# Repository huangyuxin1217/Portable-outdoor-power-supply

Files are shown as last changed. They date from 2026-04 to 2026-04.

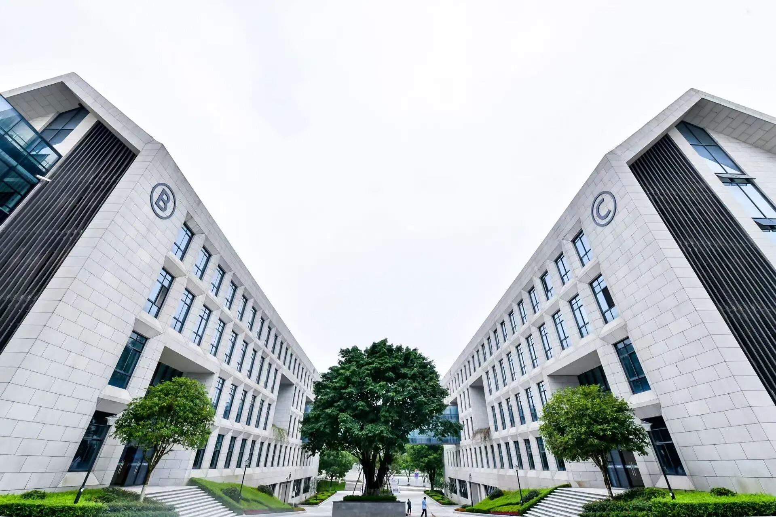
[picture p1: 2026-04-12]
Paper Sculpture Lamp Design/png/微信图片_2025-12-22_202631_440.jpg

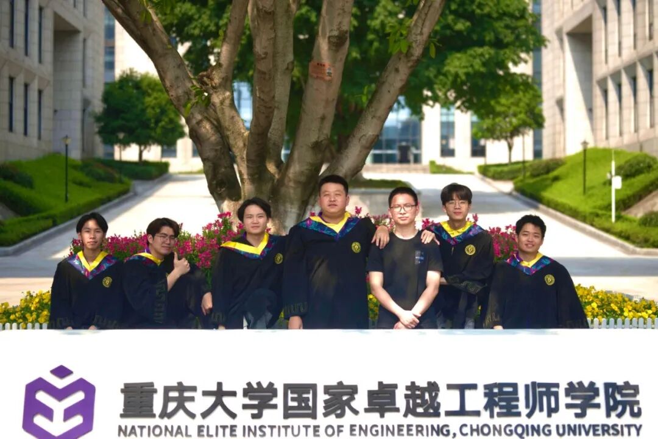
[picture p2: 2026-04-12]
Paper Sculpture Lamp Design/png/640.jpg

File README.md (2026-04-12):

# control-algorithm
This is a project from my sophomore year control algorithm course, which involved building a portable outdoor power supply.Taking the DC Buck power supply engineering case as the application object, through learning methods such as theoretical calculation, simulation, and experiment, strengthen the understanding and application of automatic control theory, and complete the analysis, design, and debugging of the DC power supply control system.

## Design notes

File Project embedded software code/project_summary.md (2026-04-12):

# ESP32 控制数学系统 - 工程总结

本文档总结了当前 ESP32 控制系统的工程架构、运行流程及各核心模块的优化策略。

## 1. 工程架构 (Architecture)

本工程基于 **ESP32** 平台，采用 **FreeRTOS** 实时操作系统架构，实现了多任务并发处理。

### 核心硬件抽象层
*   **主控**: ESP32-WROOM
*   **协处理器通信**: 通过 UART2 与 STM32F103C8T6 通信 (数据采集)
*   **交互**:
    *   **输出**: 0.96寸 OLED (SSD1306), WS2812B 彩灯条, MAX98357A I2S 音频放大器
    *   **输入**: I2S 全向麦克风 (INMP441/SPH0645)

### 软件任务架构
系统通过 FreeRTOS 任务和 Arduino `loop()` 结合的方式运行：

1.  **Main Loop (Core 1)**: 负责高优先级的非阻塞逻辑
    *   Web Server 请求处理
    *   MP3 音频流播放 (`mp3->loop()`)
    *   LED 动画效果计算与刷新
    *   OLED 界面刷新 (500ms 间隔)
    *   语音指令响应逻辑
2.  **Voice Task (Core 1, Pinned)**: 语音识别专用任务
    *   持续读取 I2S 音频流
    *   执行 Edge Impulse 神经网络推理
    *   通过队列 (`voiceQueue`) 发送识别结果
3.  **STM32 Comm Task (Core 1, Pinned)**: 串口通信任务
    *   监听 UART2 接收缓冲区
    *   负责数据帧解析、校验和验证
    *   更新共享数据结构 (互斥锁保护)
4.  **WiFi Reconnect Task (Core 1, Pinned)**: 后台网络维护
    *   监控 WiFi 连接状态
    *   断线自动重连，确保主流程不卡顿

## 2. 程序运行流程 (Execution Flow)

### 2.1 启动流程
1.  **硬件初始化**: 初始化串口、LED、OLED、I2S 总线、SPIFFS 文件系统。
2.  **网络启动**: 尝试连接 WiFi (非阻塞)，成功则启动 Web Server 并播放欢迎音，失败则通过后台任务重试。
3.  **任务创建**: 启动语音识别任务、STM32 通信接收任务、WiFi 守护任务。
4.  **进入主循环**: 开始轮询处理各类事件。

### 2.2 语音控制交互流程
1.  **唤醒**: 用户说出 "Hello" -> 识别成功 -> 播放 "yes.mp3" -> 进入**激活状态** (8秒超时)。
2.  **指令**:
    *   用户说 "KaiDeng" (仅在激活状态有效) -> 打开 LED (黄色) -> 播放 "on.mp3"。
    *   用户说 "GuanDeng" (仅在激活状态有效) -> 关闭 LED -> 播放 "off.mp3"。
3.  **反馈**: 每次识别成功都会通过串口打印置信度，并在 LED 上显示简单的反馈动画（如唤醒时亮蓝灯）。

### 2.3 数据监测流程
1.  **STM32 发送**: 打包电压、电流、温度等传感器数据 -> 添加帧头/帧尾/校验 -> UART 发送。
2.  **ESP32 接收**: `stm32Task` 捕获数据 -> 校验通过 -> 更新全局 `STM32Data` 结构体。
3.  **显示更新**: 主循环每 500ms 读取一次最新数据 -> 刷新 OLED 显示屏 -> 供 Web 端 API 查询。

## 3. 各模块优化 (Optimizations)

### 3.1 语音识别 (Voice Recognition)
*   **滑动窗口机制 (Sliding Window)**: 每次推理仅更新 1/3 的音频数据，保留 2/3 旧数据。这极大提高了对跨窗口关键词的捕捉能力，避免"掐头去尾"导致的识别失败。
*   **数字增益 (Digital Gain)**: 在读取 I2S 数据时通过位移操作 (`raw >> 14`) 调整输入音量，适配不同麦克风灵敏度。
*   **激活词逻辑 (Wake Word)**: 引入 "Hello" 作为激活词，只有唤醒后才响应控制指令，有效防止日常谈话中的误触发。
*   **冷却防抖**: 识别成功后有一秒钟的“不应期”，防止一次发音被连续识别多次。

### 3.2 通信模块 (Communication)
*   **稳健协议**: 设计了包含 `帧头(AA 55)`、`长度`、`校验和`、`帧尾(0D 0A)` 的数据包格式，极大降低了串口通信的误码率和错包率。
*   **线程安全**: 使用 FreeRTOS `Mutex` (互斥锁) 保护共享数据区的读写，防止多任务并发导致的数据竞争。
*   **状态机解析**: 接收逻辑采用状态机模式，能从字节流中精准提取数据帧，具备自动丢弃乱码和错误恢复能力。

### 3.3 系统体验 (User Experience)
*   **非阻塞 WiFi**: WiFi 连接失败不会阻塞系统启动，允许设备在离线状态下正常使用语音和本地控制功能。
*   **Web 控制台**: 提供直观的网页界面 (Vue-like 风格)，支持实时数据监视、颜色拾取器、LED 动效切换和远程消息发送。
*   **OLED 动态显示**: 当收到 Web 端消息时，OLED 会暂时中断监测数据显示消息内容，10秒后自动恢复，提升交互性。

## 4. 总结
该工程成功整合了 **端侧 AI (语音)**、**实时控制 (STM32/LED)** 和 **IoT 网络 (Web)** 三大功能。代码结构清晰，通过任务分离保证了系统的实时性和稳定性，具备较高的实用价值和扩展性。

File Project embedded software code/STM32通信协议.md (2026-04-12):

# ESP32与STM32C8T6通信协议

## 📡 通信接口配置

### 硬件连接
| ESP32引脚 | 功能 | 连接到STM32 |
|---|---|---|
| GPIO16 | RX2  | STM32 TX |
| GPIO17 | TX2  | STM32 RX |
| GND | 地 | STM32 GND  |

### 通信参数
- **串口**: UART2
- **波特率**: 115200 bps
- **数据位**: 8位
- **停止位**: 1位
- **校验位**: 无
- **流控**: 无

---

## 📦 数据帧格式

### 帧结构
```
+------+------+--------+------+------+-----+------+
| 帧头 | 长度 | 数据1  | ... | 数据N | 校验 | 帧尾 |
+------+------+--------+------+------+-----+------+
  2字节  1字节  N字节          1字节  2字节
```

### 字段说明
| 字段 | 长度 | 说明 | 值/范围 |
|---|---|---|---|
| 帧头 | 2字节  | 固定帧头标识 | 0xAA 0x55 |
| 长度 | 1字节  | 数据域长度（不含帧头、校验、尾）| 0-255 |
| 数据域 | N字节  | 实际数据内容 | 见数据定义 |
| 校验 | 1字节  | 校验和（长度+数据域累加和） | 0x00-0xFF |
| 帧尾 | 2字节  | 固定帧尾标识 | 0x0D 0x0A |

---

## 📊 数据定义

### 数据包内容（共12字节数据域）
| 序号 | 参数名称 | 数据类型 | 字节数 | 单位  | 数值范围 | 说明 |
|---|---|---|---|---|---|---|
| 1 | 输出电压反馈 | uint16_t | 2字节  | 0.01V | 0-6553.5V | 高字节在前 |
| 2 | 电池电压采样 | uint16_t | 2字节  | 0.01V | 0-6553.5V | 高字节在前 |
| 3 | 输出电流采样 | uint16_t | 2字节  | 0.01A | 0-655.35A | 高字节在前 |
| 4 | 光敏传感器 | uint16_t | 2字节  | - | 0-4095 | ADC原始值，高字节在前 |
| 5 | 温度 | int16_t  | 2字节  | 0.1℃  | -327.6-327.7℃| 高字节在前，有符号 |
| 6 | 交流市电采样 | uint16_t | 2字节  | 0.1V  | 0-6553.5V | 高字节在前，RMS值  |

**总数据域长度**: 12字节

---

## 📝 完整帧示例

### 示例数据
- 输出电压: 12.34V → 1234 → 0x04D2
- 电池电压: 11.50V → 1150 → 0x047E
- 输出电流: 2.50A → 250 → 0x00FA
- 光敏传感器: 2048 → 0x0800
- 温度: 25.5℃ → 255 → 0x00FF
- 交流市电: 220.0V → 2200 → 0x0898

### 帧结构（十六进制）
```
AA 55                    // 帧头
0C                       // 长度 = 12字节
04 D2                    // 输出电压 = 1234 (12.34V)
04 7E                    // 电池电压 = 1150 (11.50V)
00 FA                    // 输出电流 = 250 (2.50A)
08 00                    // 光敏传感器 = 2048
00 FF                    // 温度 = 255 (25.5℃)
08 98                    // 交流市电 = 2200 (220.0V)
XX                       // 校验和
0D 0A                    // 帧尾
```

### 校验和计算
```c
校验和 = (0x0C + 0x04 + 0xD2 + 0x04 + 0x7E + 0x00 + 0xFA + 0x08 + 0x00 + 0x00 + 0xFF + 0x08 + 0x98) & 0xFF
```

---

## 🔄 通信流程

### STM32发送流程
1. 采集所有传感器数据
2. 按照数据定义组装数据包
3. 计算校验和
4. 添加帧头和帧尾
5. 通过UART发送完整数据帧
6. 建议发送频率: 100ms-1000ms

### ESP32接收流程
1. 监听UART2接收数据
2. 检测帧头 (0xAA 0x55)
3. 读取长度字段
4. 接收数据域
5. 读取校验和和帧尾
6. 验证校验和是否正确
7. 验证帧尾 (0x0D 0x0A)
8. 解析数据并显示/处理

---

## ⚠️ 错误处理

### 可能的错误类型
| 错误类型 | 处理方式 |
|---|---|
| 帧头错误 | 丢弃当前字节，继续搜索帧头 |
| 长度异常 | 丢弃整帧，重新等待 |
| 校验和错误 | 丢弃整帧，计数错误次数 |
| 帧尾错误 | 丢弃整帧，重新等待 |
| 超时 | 清空缓冲区，重新开始 |

### 超时设置
- **字节间超时**: 100ms（两个字节之间的最大间隔）
- **帧超时**: 500ms（从帧头到帧尾的最大时间）

---

## 📈 数据转换说明

### STM32端（发送）
```c
// 电压转换: 实际电压(V) × 100 → uint16_t
uint16_t voltage_data = (uint16_t)(actual_voltage * 100);

// 电流转换: 实际电流(A) × 100 → uint16_t
uint16_t current_data = (uint16_t)(actual_current * 100);

// 温度转换: 实际温度(℃) × 10 → int16_t
int16_t temp_data = (int16_t)(actual_temp * 10);

// 交流电压转换: 实际电压(V) × 10 → uint16_t
uint16_t ac_voltage_data = (uint16_t)(actual_ac_voltage * 10);
```

### ESP32端（接收）
```c
// 电压还原: uint16_t → 实际电压(V)
float voltage = data_u16 / 100.0f;

// 电流还原: uint16_t → 实际电流(A)
float current = data_u16 / 100.0f;

// 温度还原: int16_t → 实际温度(℃)
float temp = data_i16 / 10.0f;

// 交流电压还原: uint16_t → 实际电压(V)
float ac_voltage = data_u16 / 10.0f;
```

---

## 🔧 扩展说明

### 预留扩展
如需增加更多数据，建议：
1. 保持帧头、帧尾、校验算法不变
2. 修改长度字段
3. 在数据域末尾添加新数据
4. 更新本协议文档
5. 保持版本兼容性考虑

### 版本管理
- **当前版本**: V1.0
- **更新日期**: 2025年12月19日
- **维护者**: ESP32控制数学系统项目组

---

## 📌 注意事项

1. **字节序**: 所有多字节数据采用**大端模式**（高字节在前）
2. **数据对齐**: 无需特殊对齐，按顺序排列
3. **异常值**: 当传感器异常时，建议发送特定值（如0xFFFF）表示无效
4. **通信质量**: 建议添加通信成功率统计，便于调试
5. **调试模式**: 建议STM32和ESP32都提供串口输出用于调试验证

---

## 🎯 下一步工作

- [ ] 在ESP32端实现UART2接收解析函数
- [ ] 在ESP32端实现数据结构体定义
- [ ] 在OLED上显示接收到的数据
- [ ] 实现错误检测和统计
- [ ] 添加数据变化监测和告警功能
- [ ] 通过WiFi将数据上传到Web界面

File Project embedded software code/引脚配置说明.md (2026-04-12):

# ESP32 控制数学系统 - 引脚配置说明

## 项目信息
- **开发板**: MH-ET ESP32 DevKit
- **芯片**: ESP32-WROOM-32
- **开发环境**: PlatformIO + Arduino Framework

---

## 引脚配置表

### OLED显示屏 (I2C接口)
| 功能 | ESP32引脚 | 说明 |
|---|---|---|
| SDA | GPIO21 | I2C数据线 (默认I2C引脚) |
| SCL | GPIO22 | I2C时钟线 (默认I2C引脚) |
| VCC | 3.3V | 电源正极 |
| GND | GND | 电源地 |

**OLED规格**:
- 型号: SSD1306 / SSD1309
- 尺寸: 0.96寸 / 2.42寸
- 分辨率: 128x64
- I2C地址: 0x3C

---

### 麦克风 (I2S接口 - INMP441)
| 功能 | ESP32引脚 | 说明 |
|---|---|---|
| SCK  | GPIO26 | 串行时钟 (BCLK) |
| WS | GPIO25 | 字选择 (LRCK) |
| SD | GPIO34 | 串行数据 (DOUT) |
| VCC  | 3.3V | 电源正极 |
| GND  | GND | 电源地 |
| L/R  | GND | 接地选择左声道 (或根据代码配置) |

### LED指示灯
| 功能 | ESP32引脚 | 说明 |
|---|---|---|
| LED  | GPIO2 | 板载蓝色LED (高电平亮/低电平亮视板子而定) |

### WS2812B 彩灯 (预留)
| 功能 | ESP32引脚 | 说明 |
|---|---|---|
| DIN  | GPIO27 | 灯带数据输入 |
| VCC  | 5V | 灯带电源 (注意功率) |
| GND  | GND | 电源地 |

### 扬声器 / 功放 (I2S接口 - MAX98357A)
| 功能 | ESP32引脚 | 说明 |
|---|---|---|
| LRC  | GPIO33 | 字选择 (LRCK) |
| BCLK | GPIO32 | 串行时钟 (BCLK) |
| DIN  | GPIO23 | 串行数据输入 (DIN) |
| VCC  | 5V | 电源正极 |
| GND  | GND | 电源地 |

---

### 串口通信

#### UART0 (USB串口 - 调试用)
| 功能 | ESP32引脚 | 说明 |
|---|---|---|
| TX | GPIO1 (TXD0) | USB转串口发送 |
| RX | GPIO3 (RXD0) | USB转串口接收 |

**用途**: 程序下载、串口调试监视器
**波特率**: 115200

#### UART2 (与 STM32 通信 - 预留)
| 功能 | ESP32引脚 | 说明 |
|---|---|---|
| TX | GPIO17 (TX2) | 发送数据给 STM32 |
| RX | GPIO16 (RX2) | 接收 STM32 数据 |

**用途**: 与 STM32 核心板进行数据交互
**状态**: 预留可用

---

### WiFi 通信
| 功能 | 说明 |
|---|---|
| WiFi模块 | ESP32内置WiFi (2.4GHz) |
| 支持模式 | STA (客户端模式) / AP (热点模式) / STA+AP |
| 当前模式 | STA模式 - 连接到路由器 |
| 占用引脚 | 无需外部引脚 (内部集成) |

**功能**: 
- 连接到WiFi路由器
- 与手机/电脑进行网络通信
- 支持HTTP服务器、TCP/UDP通信

---

## 可用引脚 (未占用)

以下引脚可用于扩展功能:

| 引脚编号 | 类型 | 备注 |
|---|---|---|
| GPIO4 | 输入/输出 | 可用 |
| GPIO5 | 输入/输出 | 可用 |
| GPIO12-15 | 输入/输出 | 启动时需注意电平状态 (MTDI/MTDO等) |
| GPIO18-19 | 输入/输出 | 可用 (VSPI引脚) |
| GPIO35-39 | 仅输入/ADC | 仅输入，支持模拟输入 (GPIO34已用于麦克风) |

---

## 注意事项

### 不可用或受限引脚
- **GPIO0**: 启动模式选择，启动时需为高电平
- **GPIO2**: 启动时需为低电平，板载LED
- **GPIO6-11**: 连接到Flash芯片，**禁止使用**
- **GPIO34-39**: 仅输入，无内部上拉/下拉电阻 

### 电源说明
- **工作电压**: 3.3V逻辑电平
- **供电方式**: USB 5V供电 (板载稳压至3.3V)
- **最大输出电流**: 单个GPIO约40mA，总电流不超过200mA

---

## 功能模块说明

### 1. OLED显示模块
**文件位置**: 
- `include/oled.h` - 头文件
- `src/oled.cpp` - 实现文件

**主要功能**:
- 显示文字、数字
- 绘制图形（线、矩形、圆形）
- 屏幕刷新控制

### 2. WiFi通信模块
**功能**: 
- STA模式连接路由器
- HTTP Web服务器
- 与手机APP进行数据交互

### 3. 串口通信模块（预留）
**用途**: 
- 外部传感器数据读取
- 与其他MCU通信
- 调试输出

---

## 更新日志
- **2025-12-19**: 初始版本，配置OLED和WiFi STA模式

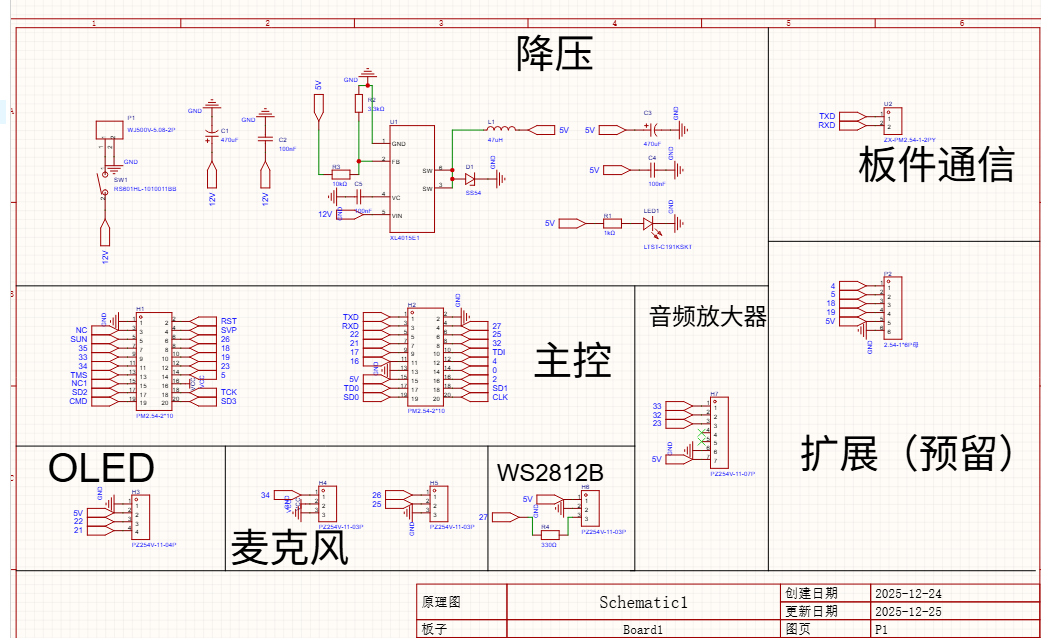
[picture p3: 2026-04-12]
Project Hardware/Schematic diagram.png

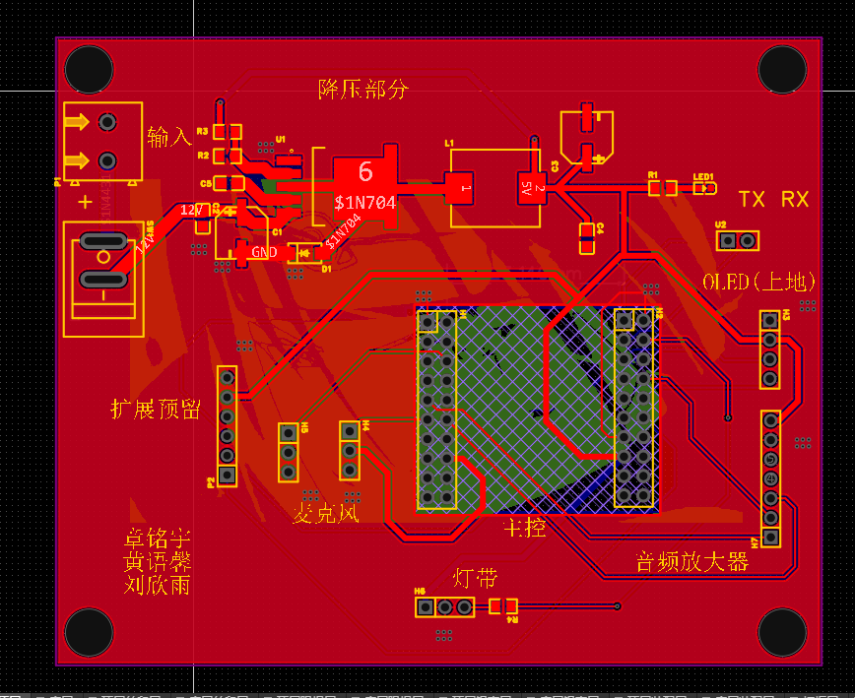
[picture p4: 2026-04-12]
Project Hardware/PCB diagram.png

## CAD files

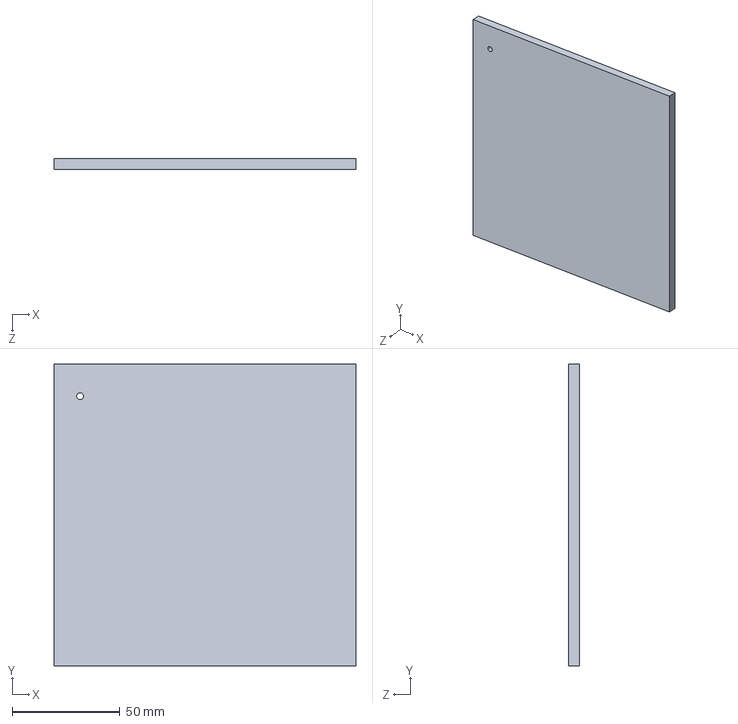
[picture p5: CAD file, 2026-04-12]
Outdoor power supply housing design/亚克力板.SLDPRT
140.0 x 140.0 x 5.00 mm

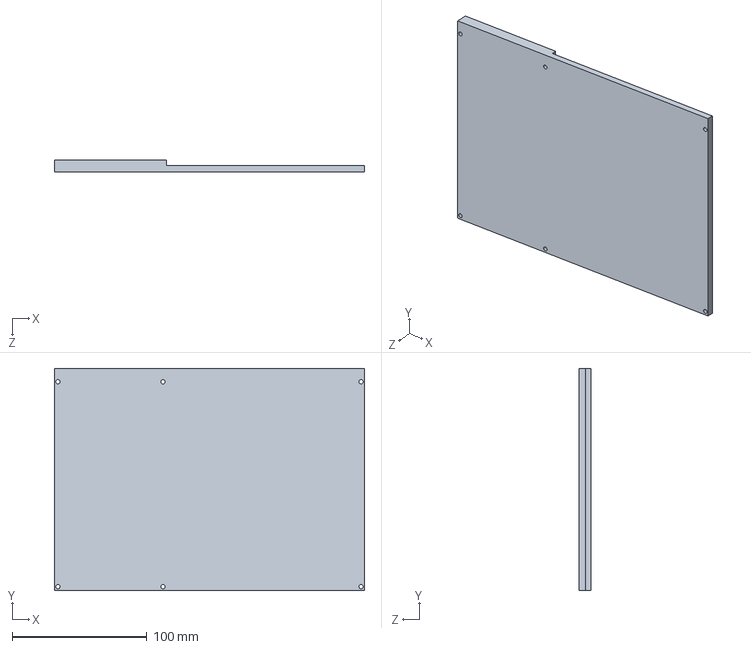
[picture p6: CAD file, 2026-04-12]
Outdoor power supply housing design/外板1.SLDPRT
230.0 x 165.0 x 9.00 mm

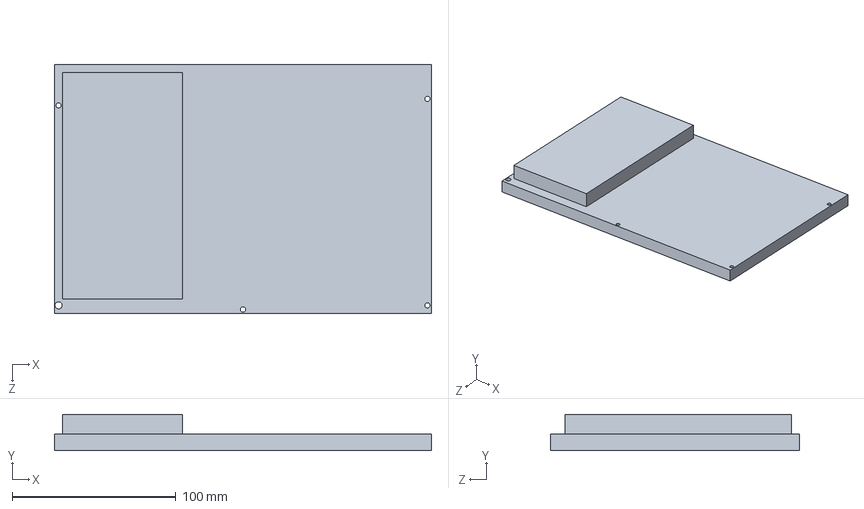
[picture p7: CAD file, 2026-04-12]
Outdoor power supply housing design/外板2.SLDPRT
230.0 x 22.0 x 152.0 mm

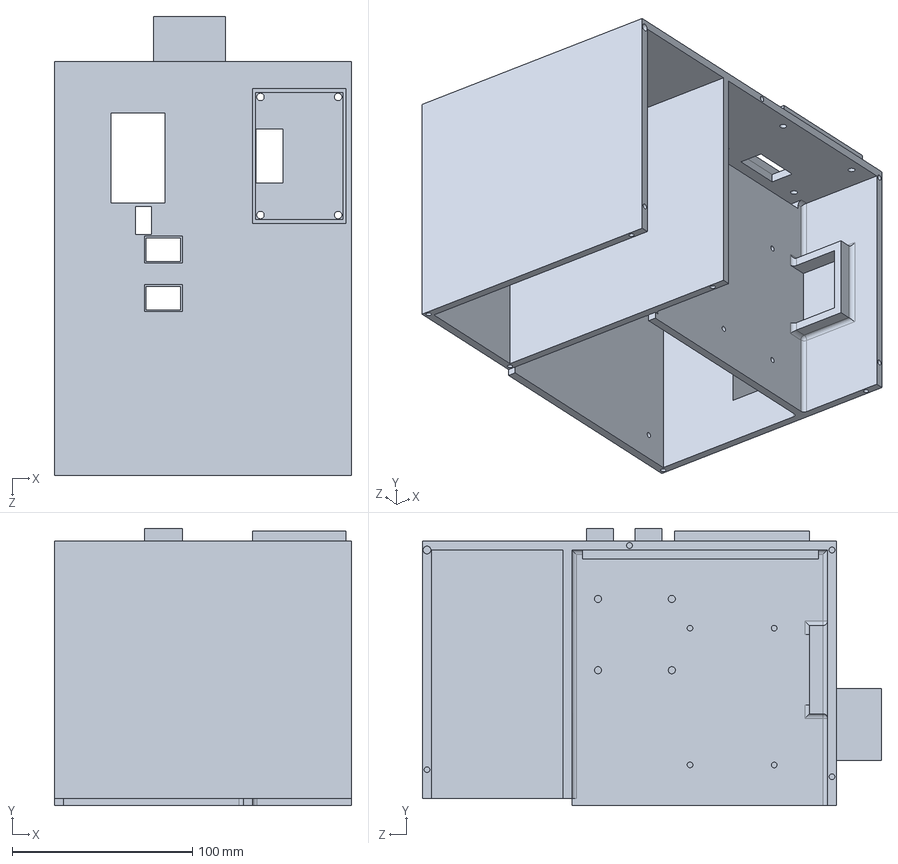
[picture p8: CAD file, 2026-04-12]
Outdoor power supply housing design/外壳1.SLDPRT
165.0 x 154.0 x 255.0 mm

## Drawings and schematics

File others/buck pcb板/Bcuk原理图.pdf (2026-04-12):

# 电源输入

5V-3.3V

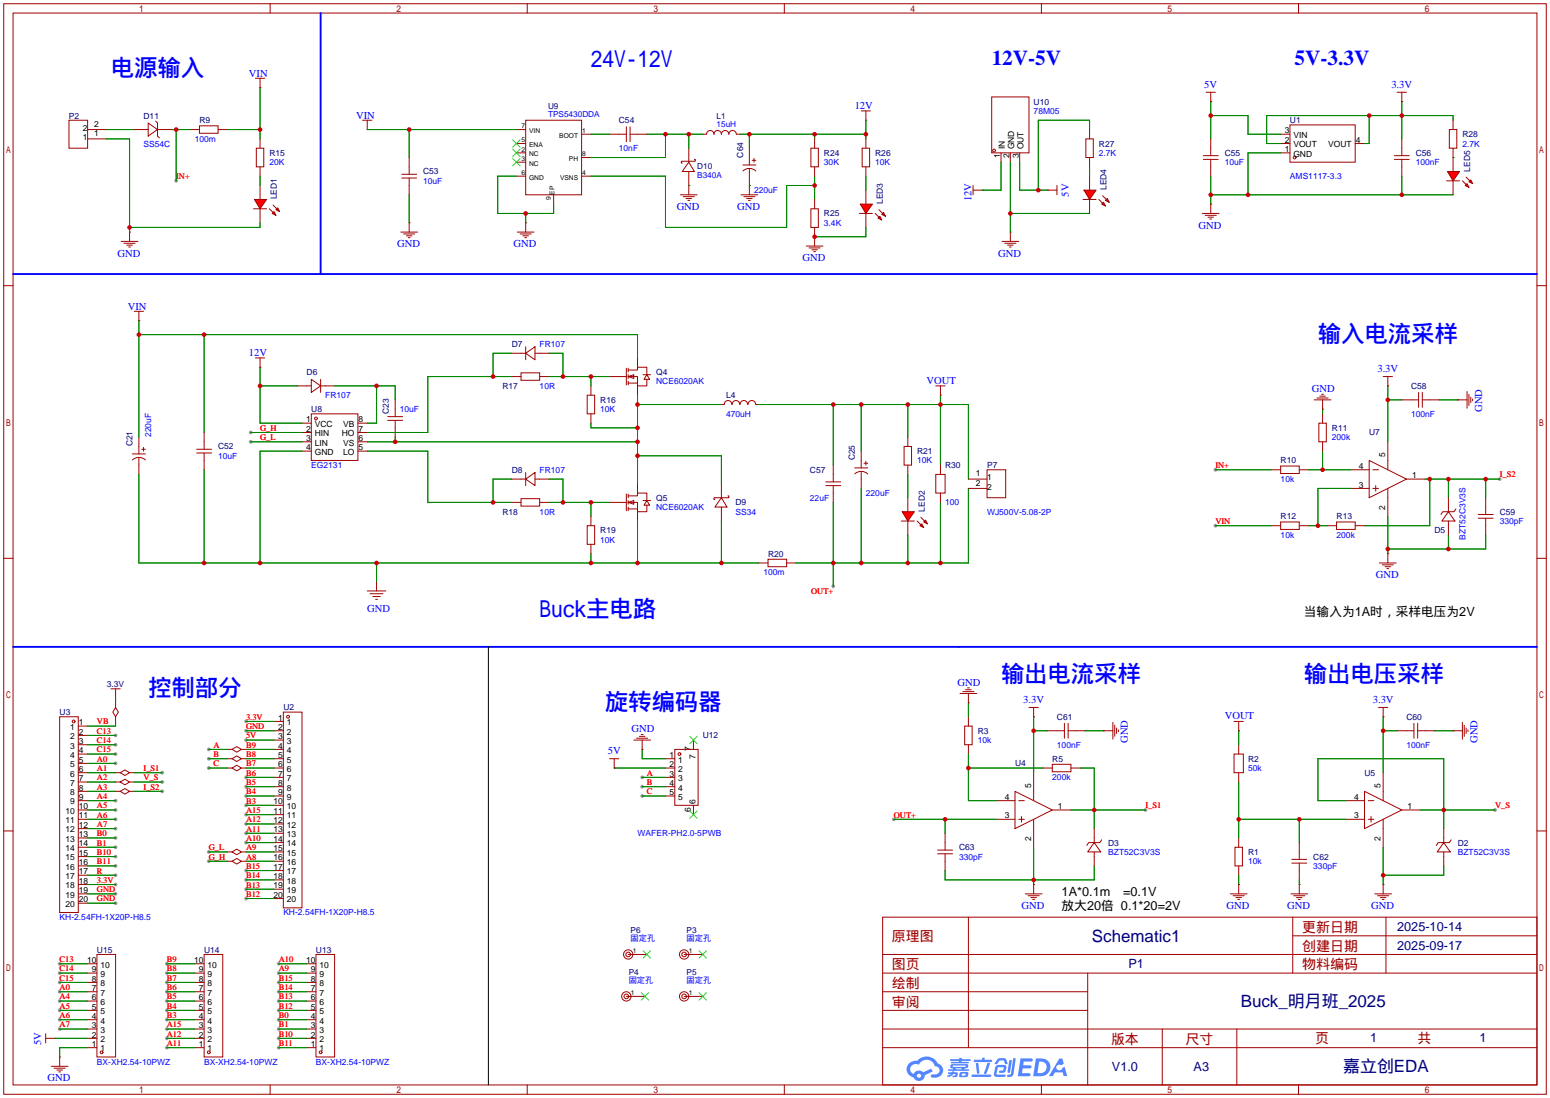
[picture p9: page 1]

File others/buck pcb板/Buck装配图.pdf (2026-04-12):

D11 L1

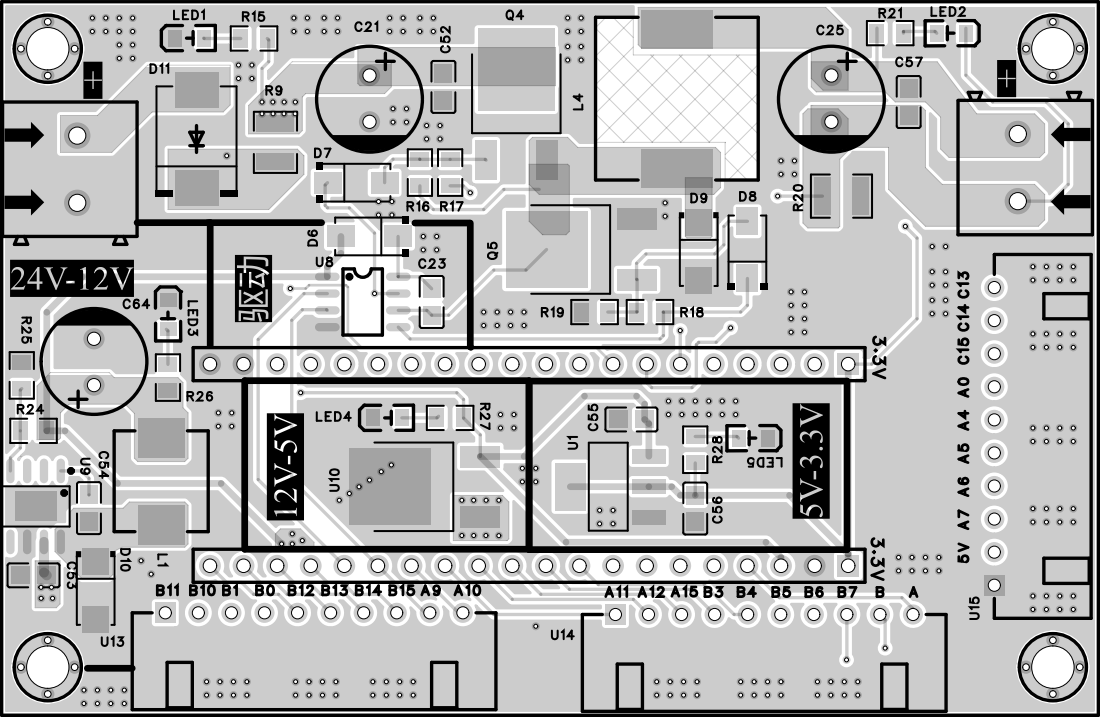
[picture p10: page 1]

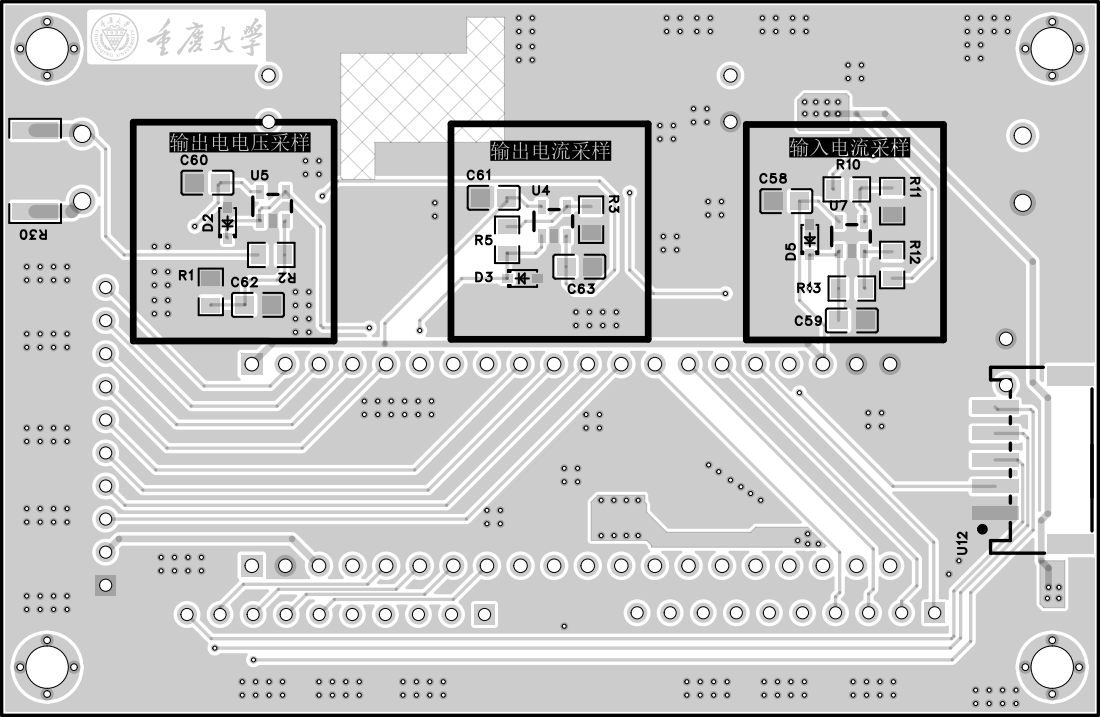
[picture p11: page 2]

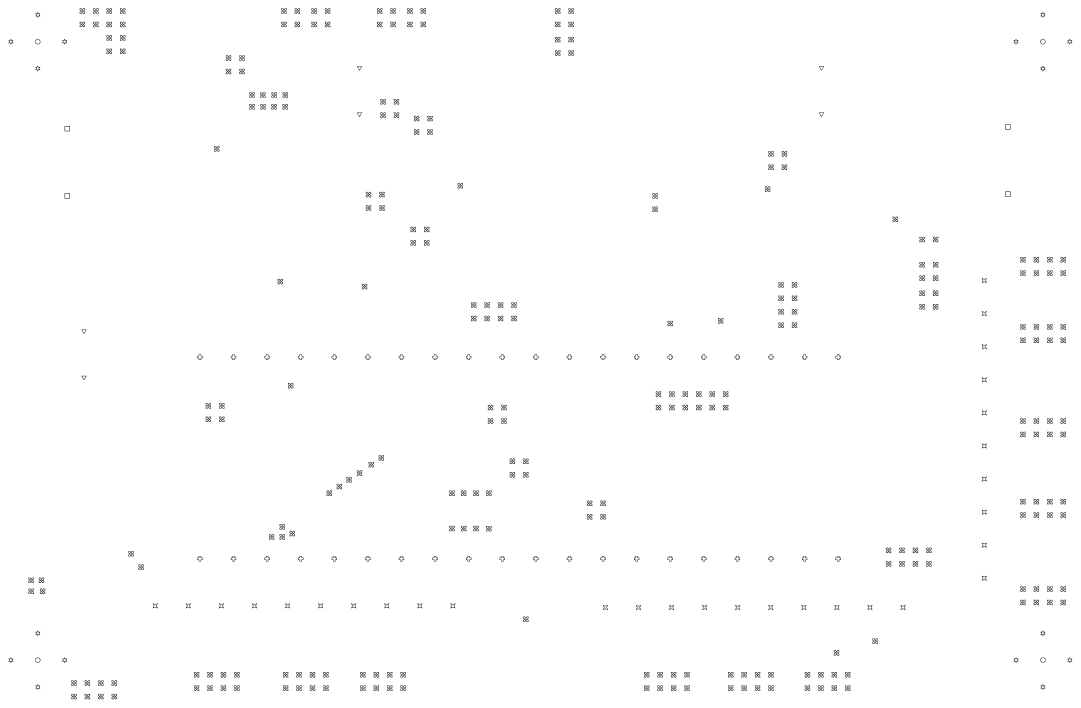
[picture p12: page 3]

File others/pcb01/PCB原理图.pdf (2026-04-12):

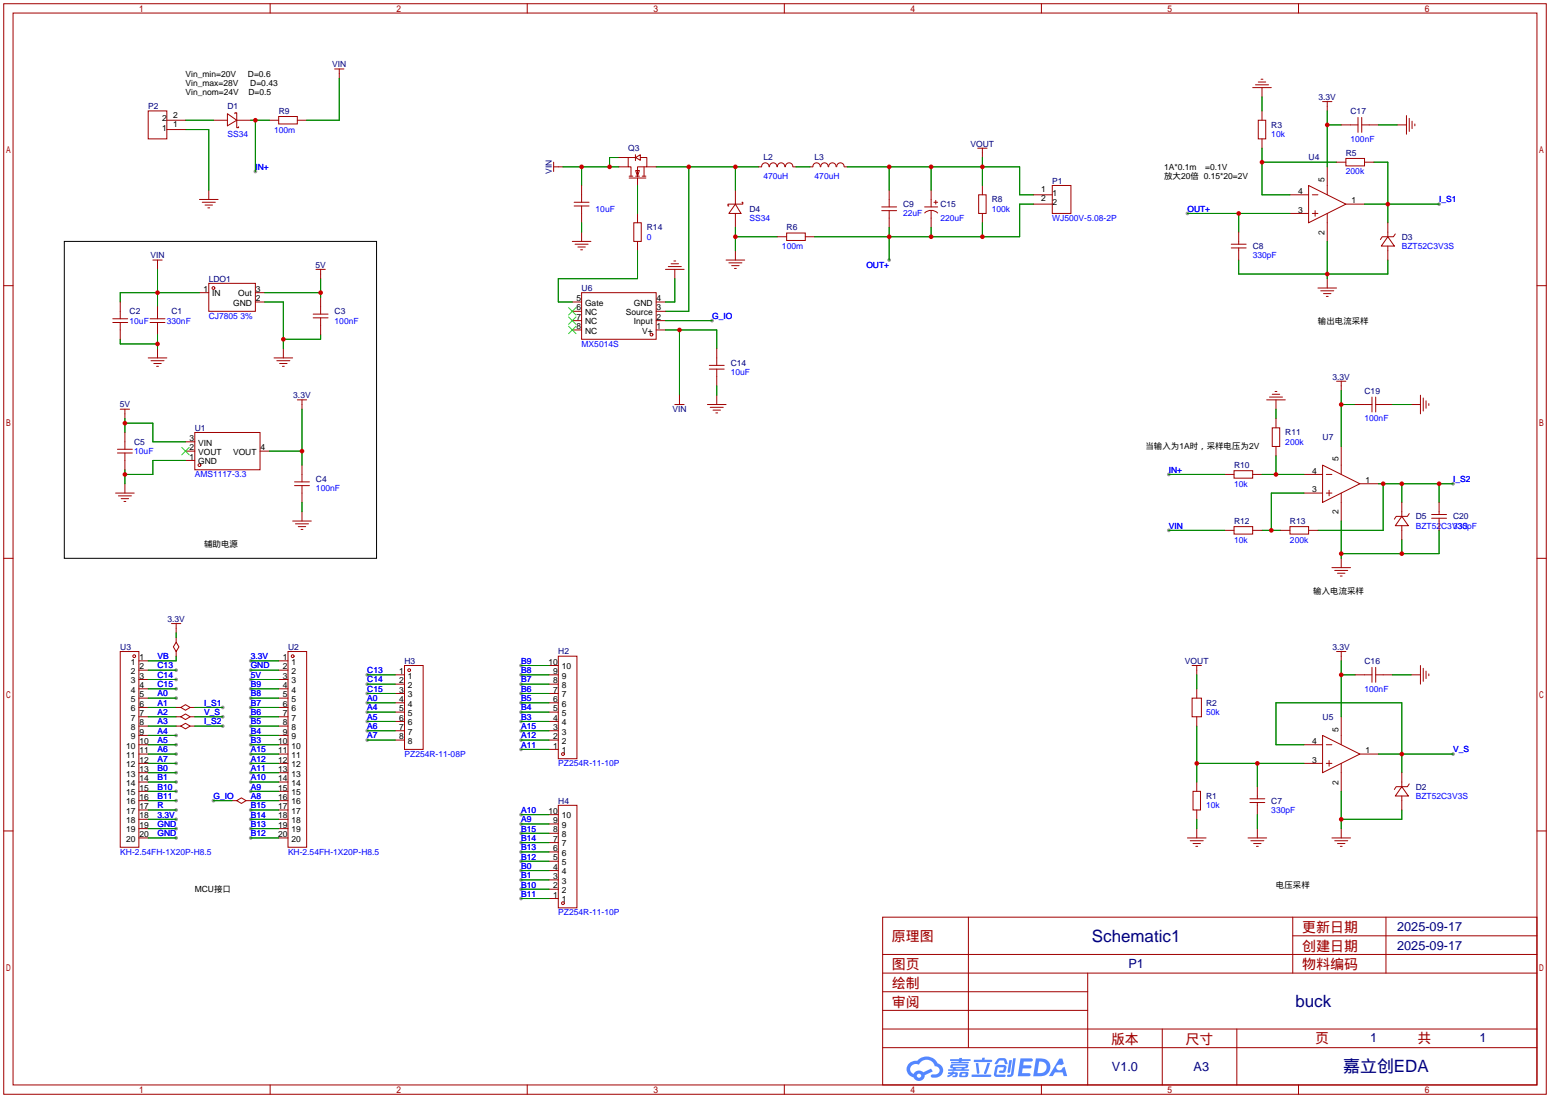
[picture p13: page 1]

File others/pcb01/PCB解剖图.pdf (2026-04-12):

V+ V-

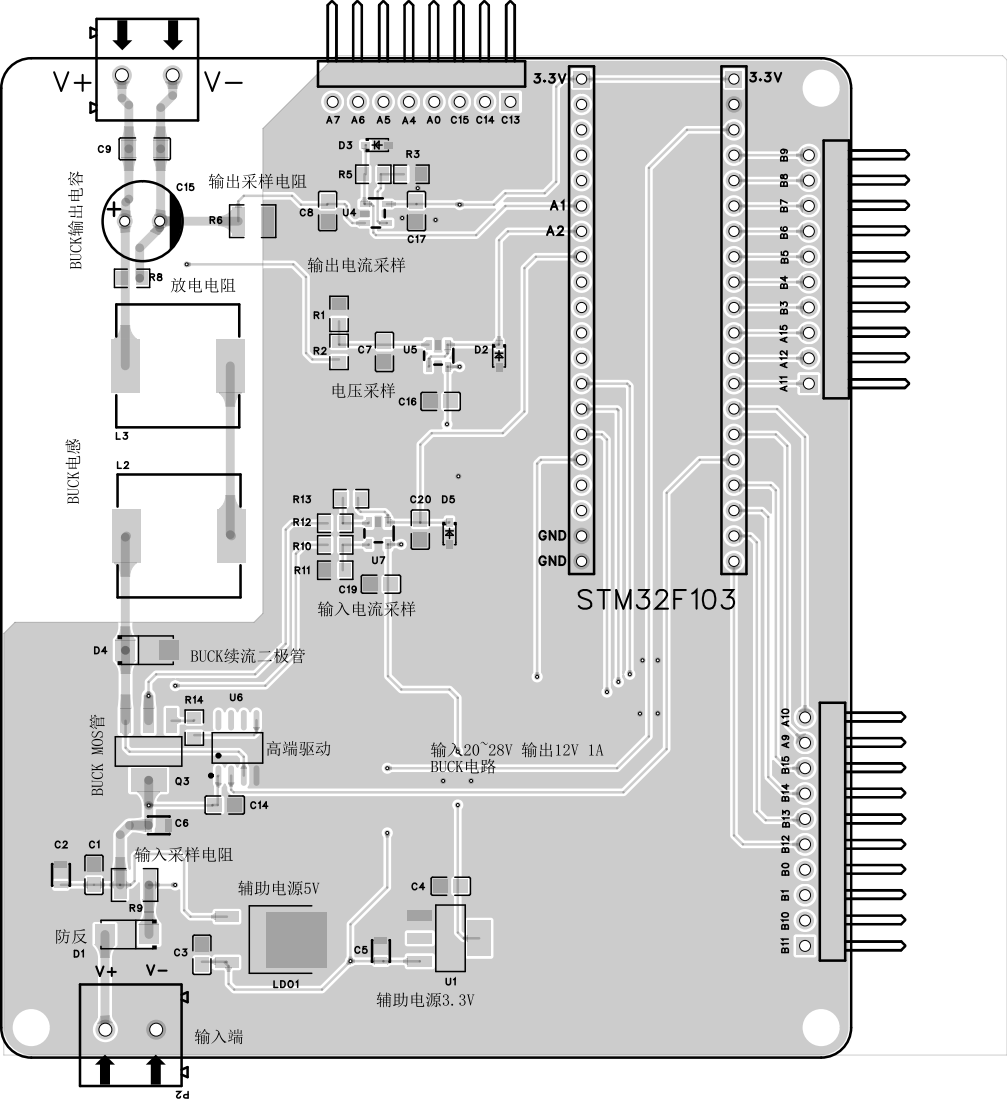
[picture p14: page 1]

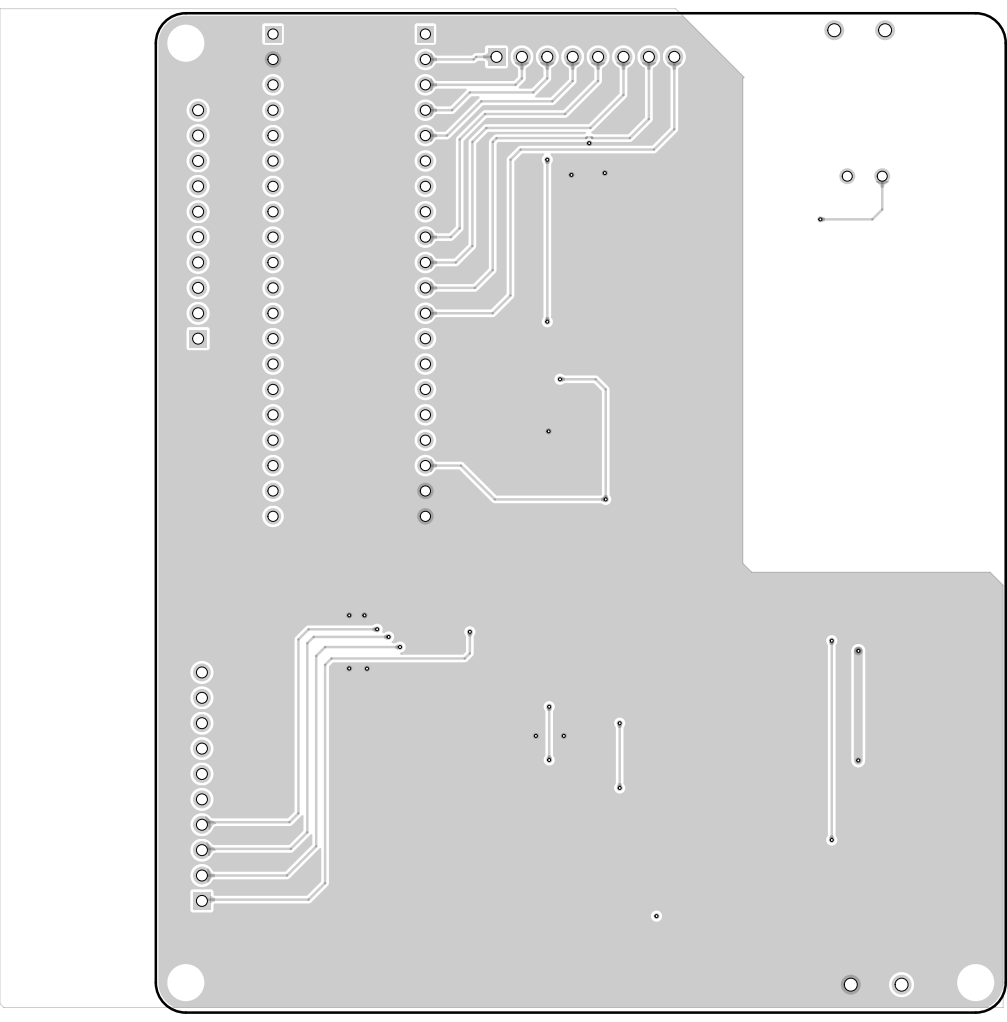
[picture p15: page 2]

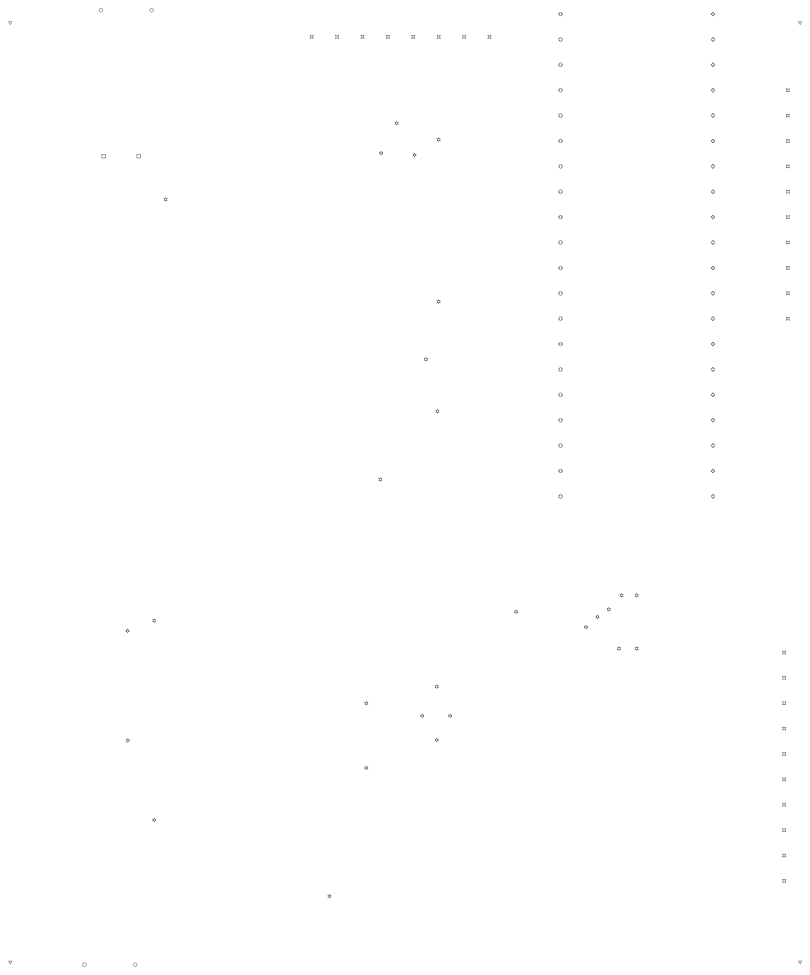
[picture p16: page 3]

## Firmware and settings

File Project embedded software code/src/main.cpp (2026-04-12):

#include <Arduino.h>
#include "oled.h"
#include "wifi_server.h"
#include "voice_recognition.h"
#include "stm32_comm.h"
#include <freertos/FreeRTOS.h>
#include <freertos/task.h>
#include <freertos/queue.h>
#include <SPIFFS.h>
#include <Adafruit_NeoPixel.h>
#include "AudioFileSourceSPIFFS.h"
#include "AudioGeneratorMP3.h"
#include "AudioOutputI2S.h"

#define LED_PIN 2
#define NEOPIXEL_PIN 27
#define NEOPIXEL_COUNT 60

Adafruit_NeoPixel strip(NEOPIXEL_COUNT, NEOPIXEL_PIN, NEO_GRB + NEO_KHZ800);

// WiFi配置
const char* ssid = "zmy";
const char* password = "zmy060521";

// LED状态
int led_state = 0;

// 语音识别开关（默认关闭）
bool voice_recognition_enabled = false;

// LED灯光效果
enum LightEffect {
    EFFECT_NONE = 0,
    EFFECT_SOLID = 1,
    EFFECT_BREATH = 2,
    EFFECT_RAINBOW = 3,
    EFFECT_GRADIENT = 4
};
int current_effect = EFFECT_NONE;
unsigned long effect_millis = 0;

// FreeRTOS 句柄
QueueHandle_t voiceQueue;
TaskHandle_t voiceTaskHandle;

// 音频对象
AudioGeneratorMP3 *mp3;
AudioFileSourceSPIFFS *file;
AudioOutputI2S *out;
bool isPlaying = false;

// I2S 引脚定义 (MAX98357A)
#define I2S_LRC     33
#define I2S_BCLK    32
#define I2S_DOUT    23

// 语音识别任务函数
void voiceTask(void *parameter) {
    while (1) {
        if (voice_recognition_enabled) {
            VoiceCommand cmd = voice_loop();
            if (cmd != CMD_NONE) {
                xQueueSend(voiceQueue, &cmd, 0);
            }
        }
        vTaskDelay(10 / portTICK_PERIOD_MS);
    }
}

// WiFi重连任务
void wifiReconnectTask(void *parameter) {
    while(1) {
        if(WiFi.status() != WL_CONNECTED) {
            Serial.println("WiFi disconnected, reconnecting...");
            WiFi.disconnect();
            delay(1000);
            WiFi.begin(ssid, password);
            
            int attempts = 0;
            while(WiFi.status() != WL_CONNECTED && attempts < 20) {
                delay(500);
                attempts++;
            }
            
            if(WiFi.status() == WL_CONNECTED) {
                Serial.println("WiFi reconnected!");
                Serial.println(WiFi.localIP());
            }
        }
        vTaskDelay(30000 / portTICK_PERIOD_MS); // 每30秒检查一次
    }
}

void playVoiceResponse(const char *filename) {
    if (mp3->isRunning()) mp3->stop();
    if (file) delete file;
    vTaskSuspend(voiceTaskHandle);
    file = new AudioFileSourceSPIFFS(filename);
    mp3->begin(file, out);
    isPlaying = true;
    Serial.printf("Playing: %s\n", filename);
}

// 计算电池电量百分比 (24V锐电池系统)
int calculateBatteryPercentage(float voltage) {
    // 24V电池系统的电压范围（6S 锂电池）
    const float VOLTAGE_MAX = 25.2;  // 满电 (4.2V x 6)
    const float VOLTAGE_MIN = 18.0;  // 空电 (3.0V x 6)
    
    if (voltage >= VOLTAGE_MAX) return 100;
    if (voltage <= VOLTAGE_MIN) return 0;
    
    // 线性插值计算百分比
    int percentage = (int)((voltage - VOLTAGE_MIN) / (VOLTAGE_MAX - VOLTAGE_MIN) * 100);
    return constrain(percentage, 0, 100);
}

void setup() {
    Serial.begin(115200);
    delay(2000);
    
    Serial.println("\n=================================");
    Serial.println("ESP32 Control Math System START");
    Serial.println("=================================\n");
    
    pinMode(LED_PIN, OUTPUT);
    
    // WS2812B 初始化 - 直连版本（已移除电阻）
    strip.begin();
    strip.setBrightness(30);
    strip.clear();
    strip.show();
    Serial.println("WS2812B initialized (direct connection)");

    // OLED初始化
    OLED_Init();
    
    // 语音识别
    voice_setup();
    
    // SPIFFS和音频
    if (!SPIFFS.begin(true)) {
        Serial.println("SPIFFS Mount Failed");
    }
    out = new AudioOutputI2S(1, AudioOutputI2S::EXTERNAL_I2S);
    out->SetPinout(I2S_BCLK, I2S_LRC, I2S_DOUT);
    out->SetGain(3.5);  // 提高音频输出音量
    mp3 = new AudioGeneratorMP3();
    
    // STM32通信
    STM32_Init();
    
    // FreeRTOS队列和任务
    voiceQueue = xQueueCreate(5, sizeof(VoiceCommand));
    xTaskCreatePinnedToCore(voiceTask, "VoiceTask", 8192, NULL, 1, &voiceTaskHandle, 0);
    
    // WiFi - 失败不阻塞
    WiFi_Init(ssid, password);
    if(WiFi.status() == WL_CONNECTED) {
        WebServer_Init();
        playVoiceResponse("/web_init.mp3");  // 播放Web初始化成功提示音
        Serial.println("=================================\n");
    } else {
        Serial.println("WiFi init failed, will retry in background");
    }
    
    // 启动WiFi重连任务
    xTaskCreatePinnedToCore(wifiReconnectTask, "WiFiReconnect", 4096, NULL, 1, NULL, 1);
}

unsigned long lastOledUpdate = 0;
const unsigned long OLED_INTERVAL = 500;

void loop() {
    WebServer_Handle();

    VoiceCommand cmd;
    if (xQueueReceive(voiceQueue, &cmd, 0) == pdTRUE) {
        if (cmd == CMD_HELLO) {
            playVoiceResponse("/yes.mp3"); // 播放yes.mp3语音提示
            Serial.println("Voice Command: HELLO (Activated)");
            for(int i=0; i<10; i++) {
                strip.setPixelColor(i, strip.Color(0, 50, 255));
            }
            strip.show();
            delay(200);
            if (led_state == 0) {
                strip.clear();
                strip.show();
            }
        } else if (cmd == CMD_KAIDENG) {
            Serial.println("Voice Command: ON");
            if (led_state == 0) {
                // 只有在灯关闭时才执行开灯并播放语音
                led_state = 1;
                pinMode(LED_PIN, OUTPUT);
                digitalWrite(LED_PIN, HIGH);
                // 默认开灯为黄色
                for(int i=0; i<strip.numPixels(); i++) {
                    strip.setPixelColor(i, strip.Color(255, 255, 0));
                }
                strip.show();
                playVoiceResponse("/on.mp3");
            } else {
                Serial.println("LED already ON, skipping voice response");
            }
        } else if (cmd == CMD_GUANDENG) {
            Serial.println("Voice Command: OFF");
            if (led_state == 1) {
                // 只有在灯开启时才执行关灯并播放语音
                led_state = 0;
                digitalWrite(LED_PIN, LOW);
                strip.clear();
                strip.show();
                playVoiceResponse("/off.mp3");
            } else {
                Serial.println("LED already OFF, skipping voice response");
            }
        }
    }

    // 音频播放处理
    if (mp3->isRunning()) {
        if (!mp3->loop()) {
            mp3->stop();
            isPlaying = false;
            vTaskResume(voiceTaskHandle);
            Serial.println("Playback finished");
            
            // 恢复LED状态
            pinMode(LED_PIN, OUTPUT);
            digitalWrite(LED_PIN, led_state ? HIGH : LOW);
            if (led_state) {
                for(int i=0; i<strip.numPixels(); i++) {
                    strip.setPixelColor(i, strip.Color(255, 255, 0));
                }
                strip.show();
            }
        }
    }
    
    // LED灯光效果处理
    if (led_state && current_effect != EFFECT_NONE && current_effect != EFFECT_SOLID) {
        unsigned long now = millis();
        
        if (current_effect == EFFECT_BREATH) {
            // 呼吸灯效果
            float breath = (exp(sin((now - effect_millis) / 2000.0 * PI)) - 0.36787944) * 108.0;
            int brightness = (int)breath;
            for(int i=0; i<strip.numPixels(); i++) {
                strip.setPixelColor(i, strip.Color(brightness, brightness, brightness));
            }
            strip.show();
        } else if (current_effect == EFFECT_RAINBOW) {
            // 彩虹灯效果
            uint16_t hue = (now - effect_millis) / 10 % 65536;
            for(int i=0; i<strip.numPixels(); i++) {
                strip.setPixelColor(i, strip.gamma32(strip.ColorHSV(hue + (i * 65536L / strip.numPixels()))));
            }
            strip.show();
        } else if (current_effect == EFFECT_GRADIENT) {
            // 渐变灯效果
            uint16_t hue = (now - effect_millis) / 20 % 65536;
            uint32_t color = strip.gamma32(strip.ColorHSV(hue));
            for(int i=0; i<strip.numPixels(); i++) {
                strip.setPixelColor(i, color);
            }
            strip.show();
        }
    }
    
    // OLED更新
    if (!isPlaying && (millis() - lastOledUpdate > OLED_INTERVAL)) {
        lastOledUpdate = millis();
        UpdateMessageDisplay();
        
        if(!IsShowingMessage()) {
            OLED_NewFrame();
            OLED_PrintASCIIString(0, 0, led_state ? "LED: ON " : "LED: OFF", &afont8x6, OLED_COLOR_NORMAL);

            STM32Data stmData;
            if (STM32_GetData(&stmData)) {
                char buf[20];
                snprintf(buf, sizeof(buf), "Vo:%.1fV", stmData.output_voltage);
                OLED_PrintASCIIString(0, 12, buf, &afont8x6, OLED_COLOR_NORMAL);
                snprintf(buf, sizeof(buf), "Io:%.2fA", stmData.output_current);
                OLED_PrintASCIIString(64, 12, buf, &afont8x6, OLED_COLOR_NORMAL);
                
                // 电池电压和电量百分比
                int batteryPct = calculateBatteryPercentage(stmData.battery_voltage);
                snprintf(buf, sizeof(buf), "Bat:%.1fV %d%%", stmData.battery_voltage, batteryPct);
                OLED_PrintASCIIString(0, 24, buf, &afont8x6, OLED_COLOR_NORMAL);
                
                snprintf(buf, sizeof(buf), "T:%.1fC", stmData.temperature);
                OLED_PrintASCIIString(0, 36, buf, &afont8x6, OLED_COLOR_NORMAL);
                snprintf(buf, sizeof(buf), "AC:%.0fV", stmData.ac_voltage);
                OLED_PrintASCIIString(64, 36, buf, &afont8x6, OLED_COLOR_NORMAL);
            } else {
                OLED_PrintASCIIString(0, 20, "Waiting for STM32...", &afont8x6, OLED_COLOR_NORMAL);
            }
            
            char ip[20];
            snprintf(ip, sizeof(ip), "IP:%s", WiFi.localIP().toString().c_str());
            OLED_PrintASCIIString(0, 54, ip, &afont8x6, OLED_COLOR_NORMAL);
            OLED_ShowFrame();
        }
    }
}

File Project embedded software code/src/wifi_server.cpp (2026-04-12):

#include "wifi_server.h"
#include "oled.h"
#include "stm32_comm.h"
#include <Adafruit_NeoPixel.h>

// 外部LED控制对象
extern Adafruit_NeoPixel strip;
extern int led_state;
extern int current_effect;
extern unsigned long effect_millis;
extern bool voice_recognition_enabled;
extern void playVoiceResponse(const char *filename);

// LED引脚定义
#define LED_PIN 2

// Web服务器对象
static WebServer server(80);

// 全局变量
static int counter = 0;
static int micLevel = 0;
static String receivedMessage = "";
static unsigned long messageDisplayTime = 0;
static bool showingMessage = false;

// LED颜色控制
static uint8_t led_r = 0, led_g = 255, led_b = 255;  // 默认青色

// 计算电池电量百分比（24V锂电池系统）
static int calculateBatteryPercentage(float voltage) {
    const float VOLTAGE_MAX = 25.2;  // 满电 (4.2V x 6)
    const float VOLTAGE_MIN = 18.0;  // 空电 (3.0V x 6)
    
    if (voltage >= VOLTAGE_MAX) return 100;
    if (voltage <= VOLTAGE_MIN) return 0;
    
    int percentage = (int)((voltage - VOLTAGE_MIN) / (VOLTAGE_MAX - VOLTAGE_MIN) * 100);
    return constrain(percentage, 0, 100);
}

// 处理根路径访问
static void handleRoot() {
    String html = "<!DOCTYPE html><html><head>";
    html += "<meta charset='UTF-8'>";
    html += "<meta name='viewport' content='width=device-width, initial-scale=1.0'>";
    html += "<title>ESP32 Voice Control</title>";
    html += "<style>";
    html += "body { font-family: Arial, sans-serif; margin: 20px; background: linear-gradient(135deg, #667eea 0%, #764ba2 100%); min-height: 100vh; }";
    html += ".container { max-width: 800px; margin: 0 auto; background: white; padding: 20px; border-radius: 15px; box-shadow: 0 5px 20px rgba(0,0,0,0.3); }";
    html += "h1 { color: #667eea; text-align: center; margin-bottom: 10px; }";
    html += "h2 { color: #555; font-size: 18px; border-bottom: 2px solid #667eea; padding-bottom: 5px; margin-top: 20px; }";
    html += ".info-grid { display: grid; grid-template-columns: 1fr 1fr; gap: 10px; margin: 15px 0; }";
    html += ".info-box { background: #f5f5f5; padding: 12px; border-radius: 8px; border-left: 4px solid #667eea; }";
    html += ".info-box strong { color: #667eea; display: block; font-size: 12px; }";
    html += ".info-box span { font-size: 18px; font-weight: bold; color: #333; }";
    html += ".led-status { text-align: center; font-size: 24px; padding: 15px; background: linear-gradient(90deg, #f093fb 0%, #f5576c 100%); color: white; border-radius: 10px; margin: 10px 0; }";
    html += ".btn-group { display: grid; grid-template-columns: 1fr 1fr; gap: 10px; margin: 10px 0; }";
    html += "button { padding: 15px; background: #4CAF50; color: white; border: none; border-radius: 8px; cursor: pointer; font-size: 16px; font-weight: bold; transition: 0.3s; }";
    html += "button:hover { transform: scale(1.05); box-shadow: 0 5px 15px rgba(0,0,0,0.3); }";
    html += ".btn-off { background: #f44336; } .btn-off:hover { background: #d32f2f; }";
    html += ".btn-red { background: #e74c3c; } .btn-green { background: #2ecc71; } .btn-blue { background: #3498db; }";
    html += ".btn-yellow { background: #f1c40f; } .btn-purple { background: #9b59b6; } .btn-cyan { background: #1abc9c; }";
    html += "input[type='text'] { width: 100%; padding: 12px; margin: 10px 0; box-sizing: border-box; border: 2px solid #ddd; border-radius: 8px; font-size: 14px; }";
    html += ".status-bar { background: #e3f2fd; padding: 10px; border-radius: 8px; text-align: center; margin: 10px 0; }";
    html += ".color-slider-container { margin: 15px 0; padding: 15px; background: #f9f9f9; border-radius: 10px; }";
    html += ".color-preview { width: 100%; height: 50px; border-radius: 8px; margin: 10px 0; box-shadow: 0 2px 8px rgba(0,0,0,0.2); transition: 0.3s; }";
    html += "input[type='range'] { width: 100%; height: 8px; border-radius: 5px; background: linear-gradient(to right, red, yellow, lime, cyan, blue, magenta, red); outline: none; -webkit-appearance: none; }";
    html += "input[type='range']::-webkit-slider-thumb { -webkit-appearance: none; appearance: none; width: 25px; height: 25px; border-radius: 50%; background: white; cursor: pointer; box-shadow: 0 2px 5px rgba(0,0,0,0.3); }";
    html += "input[type='range']::-moz-range-thumb { width: 25px; height: 25px; border-radius: 50%; background: white; cursor: pointer; box-shadow: 0 2px 5px rgba(0,0,0,0.3); border: none; }";
    html += "</style>";
    html += "<script>";
    html += "function updateStatus() {";
    html += "  fetch('/status').then(r => r.json()).then(d => {";
    html += "    document.getElementById('led-status').innerText = d.led_state ? 'LED ON' : 'LED OFF';";
    html += "    document.getElementById('led-status').style.background = d.led_state ? 'linear-gradient(90deg, #56CCF2 0%, #2F80ED 100%)' : 'linear-gradient(90deg, #bdc3c7 0%, #7f8c8d 100%)';";
    html += "    document.getElementById('voice-status').innerText = d.voice_enabled ? '语音识别：已开启' : '语音识别：已关闭';";
    html += "    document.getElementById('voice-status').style.background = d.voice_enabled ? 'linear-gradient(90deg, #11998e 0%, #38ef7d 100%)' : 'linear-gradient(90deg, #bdc3c7 0%, #7f8c8d 100%)';";
    html += "    document.getElementById('stm-vo').innerText = d.stm_vo;";
    html += "    document.getElementById('stm-io').innerText = d.stm_io;";
    html += "    document.getElementById('stm-bat').innerText = d.stm_bat + ' V (' + d.stm_bat_pct + '%)';";
    html += "    document.getElementById('stm-temp').innerText = d.stm_temp;";
    html += "    document.getElementById('stm-ac').innerText = d.stm_ac;";
    html += "    document.getElementById('ip').innerText = d.ip;";
    html += "    document.getElementById('uptime').innerText = Math.floor(d.uptime / 60) + 'm ' + (d.uptime % 60) + 's';";
    html += "  });";
    html += "}";
    html += "function ledControl(action) { fetch('/led?action=' + action).then(() => updateStatus()); }";
    html += "function setColor(r,g,b) { fetch('/led?color=' + r + ',' + g + ',' + b).then(() => updateStatus()); }";
    html += "function setEffect(e) { fetch('/led?effect=' + e).then(() => updateStatus()); }";
    html += "function toggleVoice() { ";
    html += "  let enabled = document.getElementById('voice-status').innerText.includes('已开启');";
    html += "  fetch('/voice?enable=' + (enabled ? '0' : '1')).then(() => updateStatus());";
    html += "}";
    html += "function hueToRgb(h) {";
    html += "  h = h / 360;";
    html += "  let r, g, b;";
    html += "  let i = Math.floor(h * 6);";
    html += "  let f = h * 6 - i;";
    html += "  let q = 1 - f;";
    html += "  switch(i % 6) {";
    html += "    case 0: r = 1; g = f; b = 0; break;";
    html += "    case 1: r = q; g = 1; b = 0; break;";
    html += "    case 2: r = 0; g = 1; b = f; break;";
    html += "    case 3: r = 0; g = q; b = 1; break;";
    html += "    case 4: r = f; g = 0; b = 1; break;";
    html += "    case 5: r = 1; g = 0; b = q; break;";
    html += "  }";
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
